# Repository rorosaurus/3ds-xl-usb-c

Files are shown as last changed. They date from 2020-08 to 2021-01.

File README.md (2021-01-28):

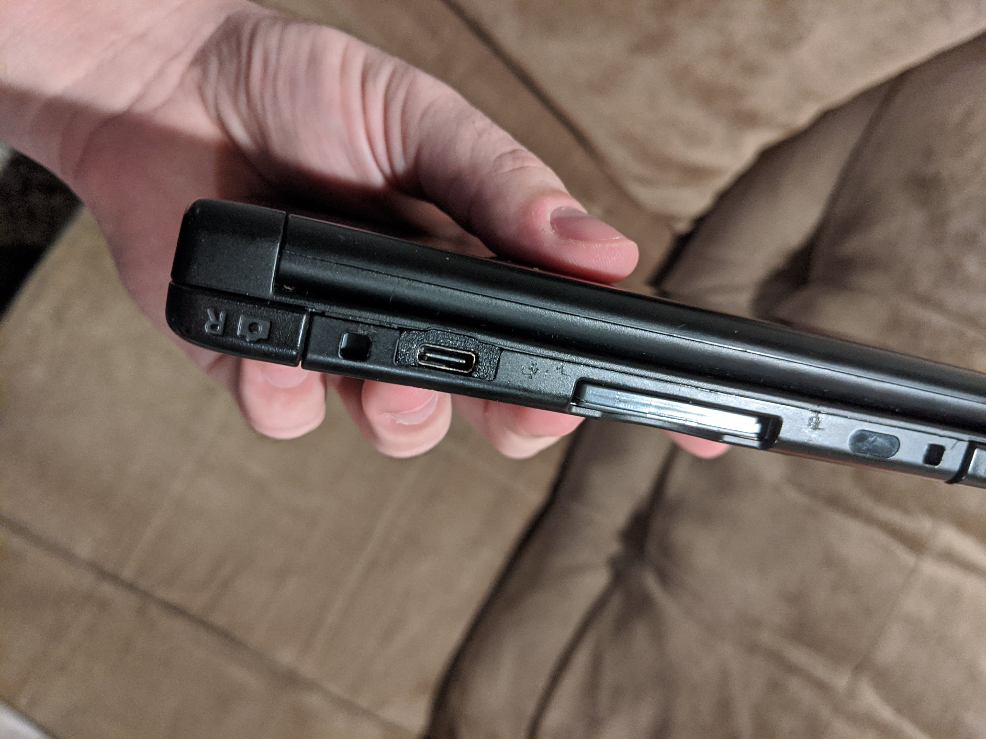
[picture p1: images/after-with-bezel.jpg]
After with bezel


**This mod requires some case trimming**, and I would recommend abandoning your charging dock contacts. More information available in the instructions page.

# Where to Buy

* USA: [Buy on Amazon](https://smile.amazon.com/dp/B08RN6LDVH) - [(Why Amazon?)](https://github.com/rorosaurus/gba-sp-usb-c/blob/master/why-sell-on-amazon.md)
* Any other Country: [Buy on Tindie](https://www.tindie.com/products/22543/) - (I will restock occasionally!)

## The truly universal USB-C dream is finally realized for your Nintendo 3DS XL!

Charge your Nintendo 3DS XL with USB-C, using any USB-C cable and charger! If it fits, it'll charge! Finally you can stop carrying around that extra proprietary cable!

My design is inspired by [this existing PCB](https://oshpark.com/shared_projects/I6UOH6gb) that only works with ````USB-A -> USB-C```` cables. In my opinion, if you're gonna future-proof your 3DS XL, you shouldn't remain reliant on Type-A!

My PCB works with ````USB-C <-> USB-C```` cables as well, so you can use ANY USB-C cable/charger to charge it! I've also verified it works with ````USB-A -> USB-C```` cables, Quick Charge, and USB-PD! That means if your charger or USB battery pack offers 5V/9V/12V/etc., it will recognize the 3DS XL can only accept 5V and charge accordingly.

**No 3D-printed part is included**, but the file is available for you to print yourself, if you want.

# Compatibility

This is designed for installation in any Nintendo 3DS XL (SPR-001).

This mod is not compatible with: 2DS, New 2DS XL, New 3DS, New 3DS XL.

This mod is not compatible with the original Nintendo 3DS. For the original 3DS, I recommend this mod by makho: [makhowastaken/3DS_C](https://github.com/makhowastaken/3DS_C/)

# Charge Speed

This console's original charger (WAP-002) outputs up to 900mA at 4.6V. According to the USB-C spec, this mod will allow charging at up to 500mA at 5V. This is, on paper, 40% slower charging than with the WAP-002.

However, in my testing, my console consumed 800mA at 5.1V, charging just as fast as the WAP-002. So please keep in mind that your mileage may vary, based on what USB charger you use and how precisely that charger follows the USB specification. Just be aware in the worst case, your console might charge a little slower.

# Disclaimer

Modify your console at your own risk! This product is provided "as is", with no warranty - express or implied. That said, if you have any issues or questions, don't hesitate to reach out!

# Installation

Instructions for assembly/installation can be found in [INSTALLATION.md](https://github.com/rorosaurus/3ds-xl-usb-c/blob/master/INSTALLATION.md)

# License

If you have improvements, please modify these design files and share any improvements openly/freely with the community (via a pull request or another public repository)!

You are not permitted to profit off of this design or use it in any commercial venture.

[Full license information.](https://github.com/rorosaurus/3ds-xl-usb-c/blob/master/LICENSE.md)

# Thanks

Thank you to [makho](https://www.youtube.com/channel/UC5FYpo9lFqK1Y7wqjPuANFw) and [BlindEye/Hidarite](https://www.tindie.com/stores/hidarite/) for the original PCB inspiration!

# Other Gameboy Mods

[Mods - Game Boy Subreddit Wiki](https://www.reddit.com/r/GameBoy/wiki/mods)

## My Other Gameboy Mods

* [USB-C Mod for Gameboy Advance SP (and original Nintendo DS)](https://github.com/rorosaurus/gba-sp-usb-c/)
* [USB-C Mod for Nintendo DS Lite](https://github.com/rorosaurus/nds-lite-usb-c/)
* [USB-C Mod for Nintendo 3DS XL](https://github.com/rorosaurus/3ds-xl-usb-c/)
* [List of headphone jack mods for the Gameboy Advance SP](https://github.com/rorosaurus/gba-sp-headphone-jack/)

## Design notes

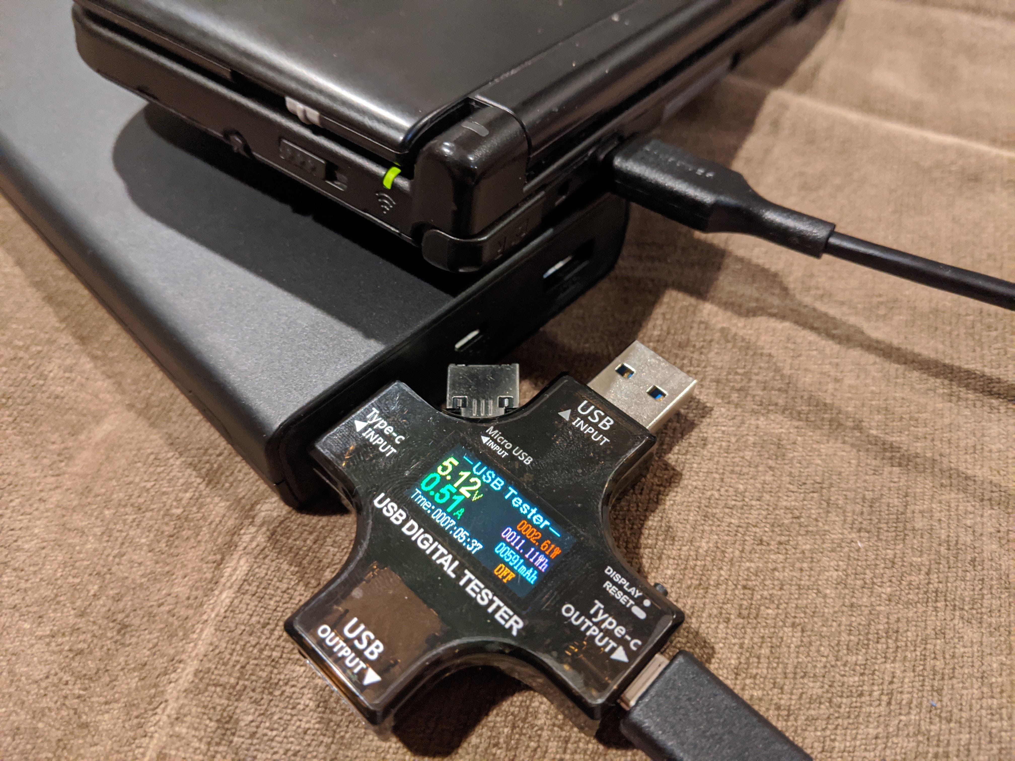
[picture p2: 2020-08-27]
images/after-charging-2.jpg

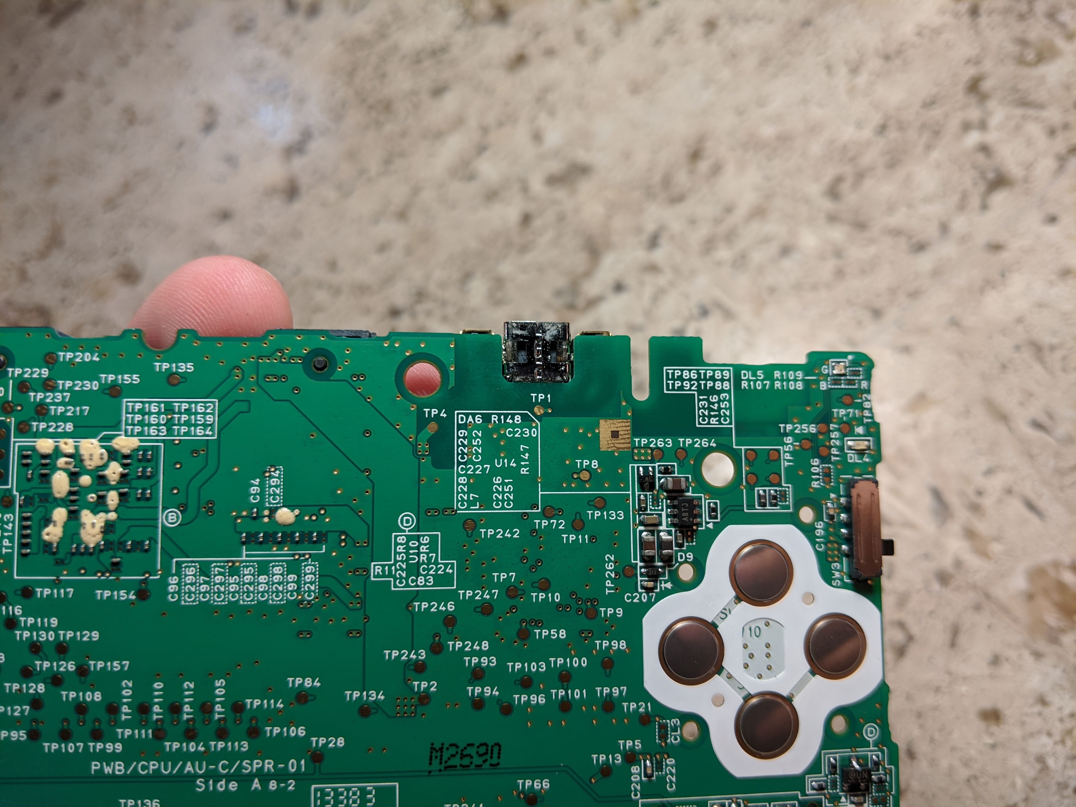
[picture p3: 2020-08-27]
images/before-port-bottom.jpg

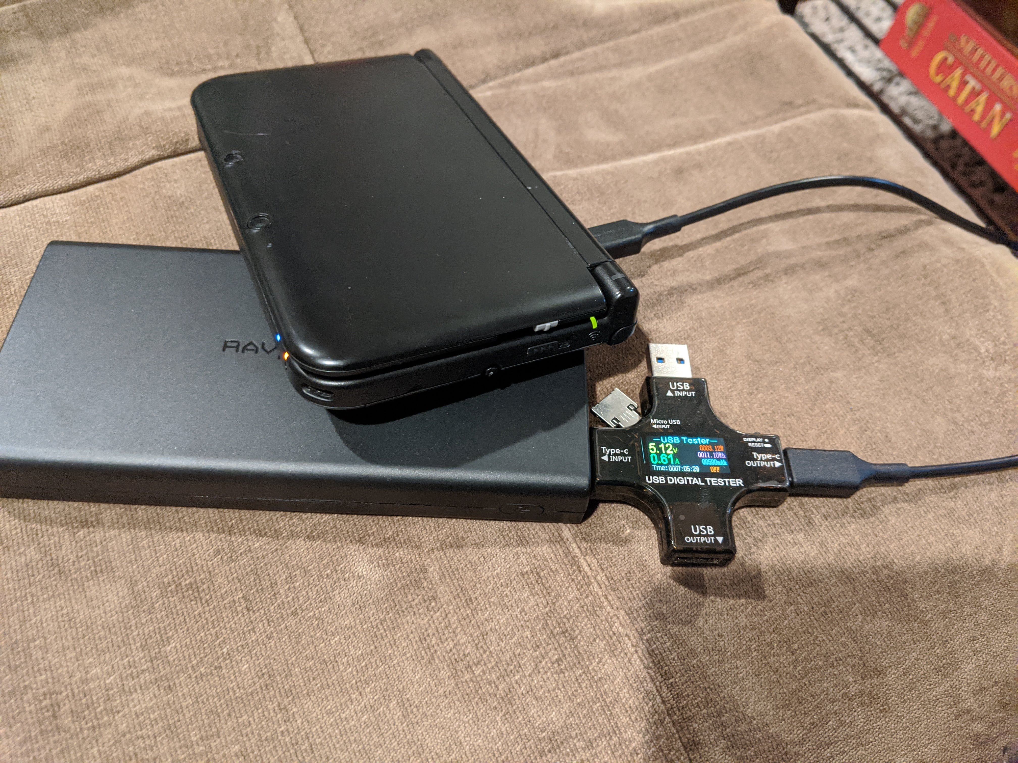
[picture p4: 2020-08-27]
images/after-charging-1.jpg

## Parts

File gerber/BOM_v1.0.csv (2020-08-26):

ID | Name | Designator | Footprint | Quantity | Manufacturer Part | Manufacturer | Supplier | Supplier Part
1 | TYPE-C-31-M-16 | USB1 | TYPE-C-SMD_TYPE-C-31-M-16 | 1
2 | 5.1K | R2,R1 | R0402 | 2

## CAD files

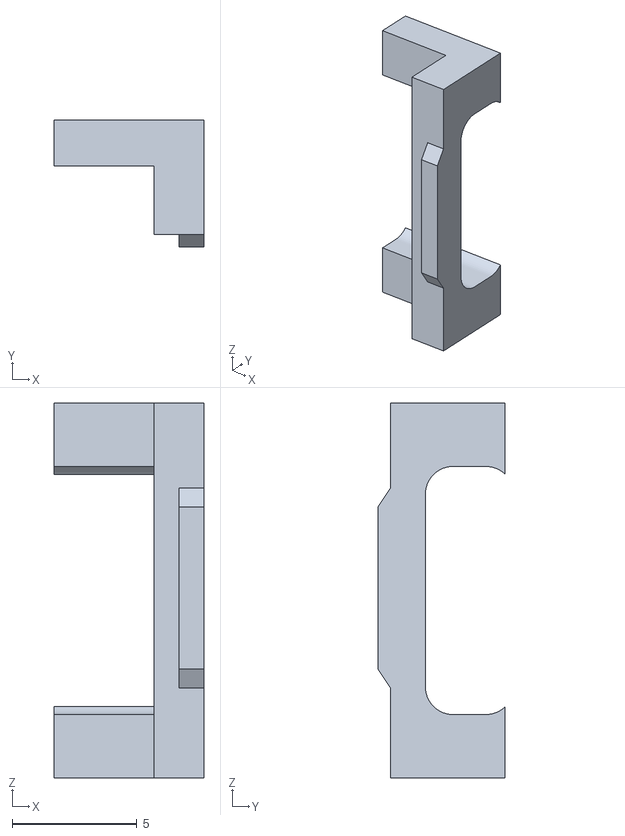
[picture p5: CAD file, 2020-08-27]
3DS-XL-USB-C-3D-printable-bezel.stl
6.00 x 5.10 x 15.0

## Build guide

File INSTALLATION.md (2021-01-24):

# Prep

Your PCBs might arrive with some [slight perforations, from the breakaway panelization design](https://github.com/rorosaurus/gba-sp-usb-c/blob/master/images/breakaway-perforations.jpg) during PCB manufacturing. These can be left alone, or optionally filed/sanded away.

The half-circle pad(s) behind the USB-C connector might have some debris across it. You can safely clear that away with a toothpick or similar - that will make it easier to solder to later.

# Test before you install!

I test every board before shipping, but you should be certain it still works before you install it! Plug it in to a ````Type-C <-> Type-C```` cable and USB-C power source. **Do not perform this test with a ````Type-A -> Type-C```` cable - that cable won't verify the board works for full USB-C!** Use a multimeter to measure the voltage across any of the grounded holes and the +5V half-circle in the back. Ensure it reads ~5V. Flip your USB-C cable the other way around and verify it still reads 5V! Alternatively, if you have a USB-C multimeter [like this](https://smile.amazon.com/gp/product/B07X3HST7V/) you can simply plug into that and read the display.

# Instructions

## A note on the charging dock contacts

I recommend abandoning the charging dock contacts if you install this mod. The USB-C port is ~8.8mm wide, the charging dock contacts are ~9.8mm apart. That means, properly centered, you'd have 0.5mm of plastic/prayers in-between your 5V dock contact and the grounded USB-C port frame. I personally don't want to deal with that likely short-circuit, but it might technically be possible if you are super careful and passionate about keeping the charging dock contacts. Make sure you harvest the contacts as you remove the standard charging port, and you'll need to modify the 3D printed bezel to accommodate those charging contacts.

## Step 1: Disassemble your 3DS XL and remove the motherboard

You can follow [this iFixit guide](https://www.ifixit.com/Guide/Nintendo+3DS+XL+Motherboard+Replacement/25399) for good disassembly instructions.

## Step 2: Remove the existing charge port

IMO, this is the hardest part by far. I found it easiest to solder-suck / wick the charging dock contacts first, then remove them.

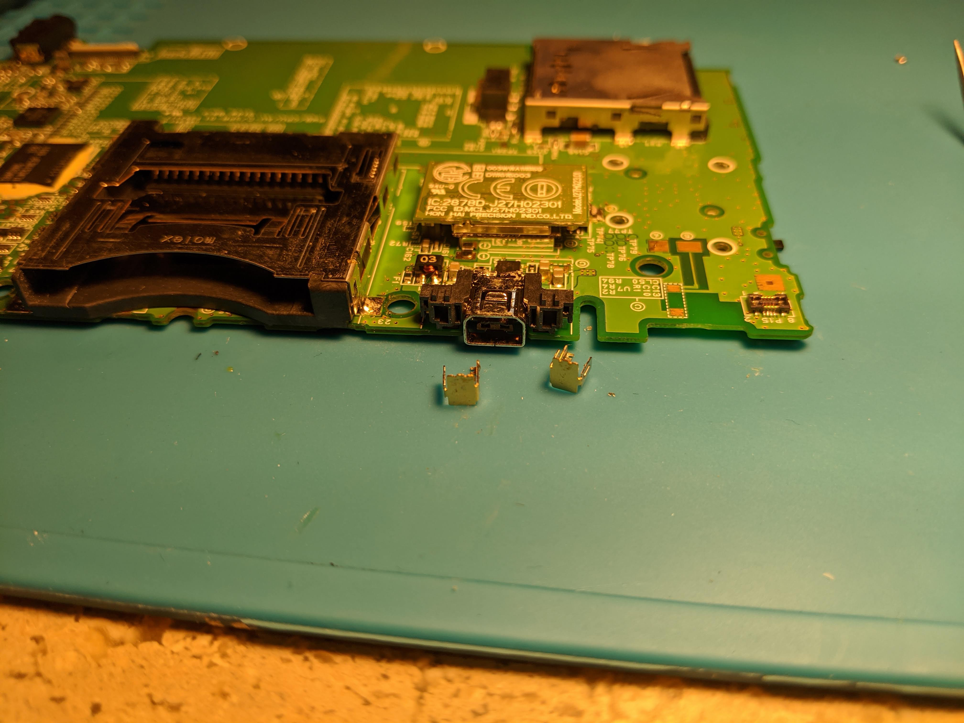
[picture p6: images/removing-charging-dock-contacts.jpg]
Removing charging dock contacts


Then I broke off and removed the charging dock contacts plastic support.

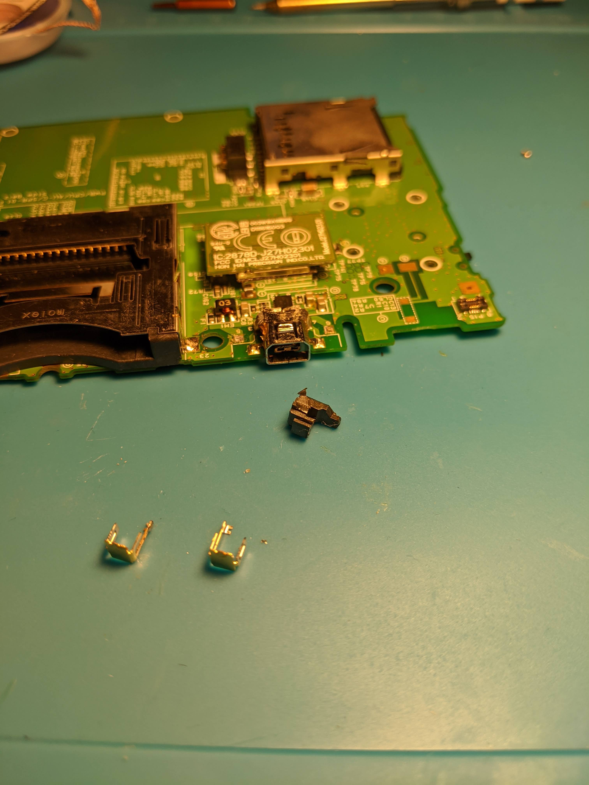
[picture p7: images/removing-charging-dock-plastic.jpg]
Removing charging dock plastic


Then I was able to solder-suck / wick the charging port itself and remove it. I should have been more patient to avoid damaging the pads a little bit.

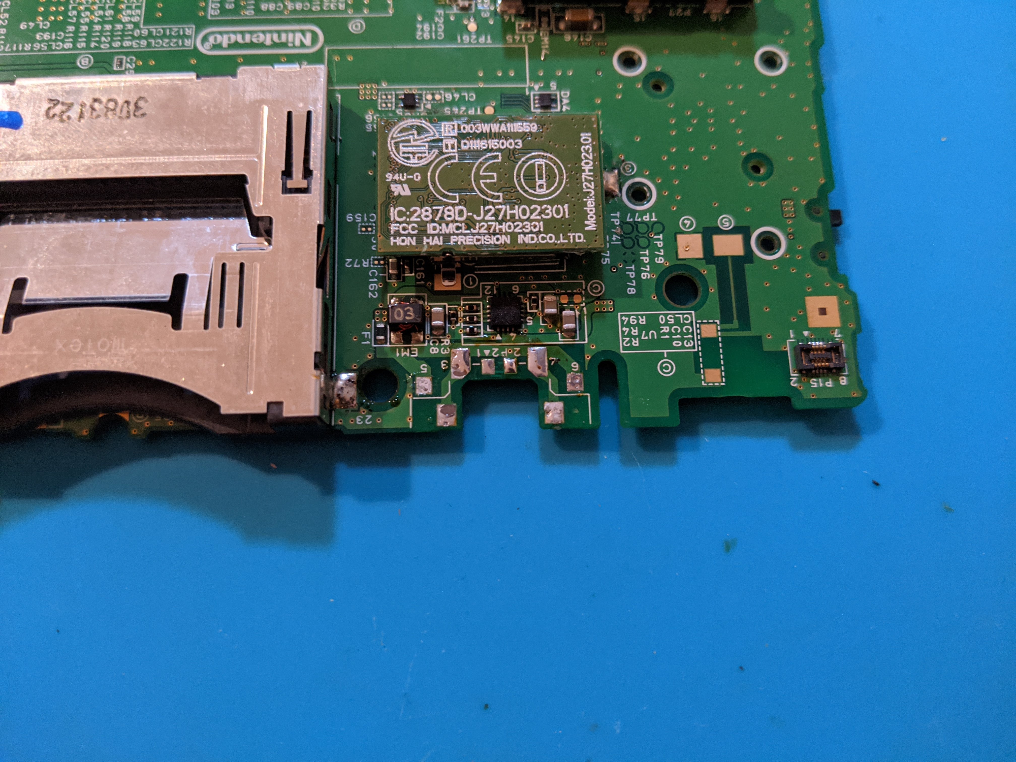
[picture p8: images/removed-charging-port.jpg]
Removed charging port


## Step 3: Prepare the new charge port

Assemble (and test!) the new USB-C charge port. That means positioning and soldering the brace into the perfect place, and adding the USB-C port and resistors if your mod came unassembled.

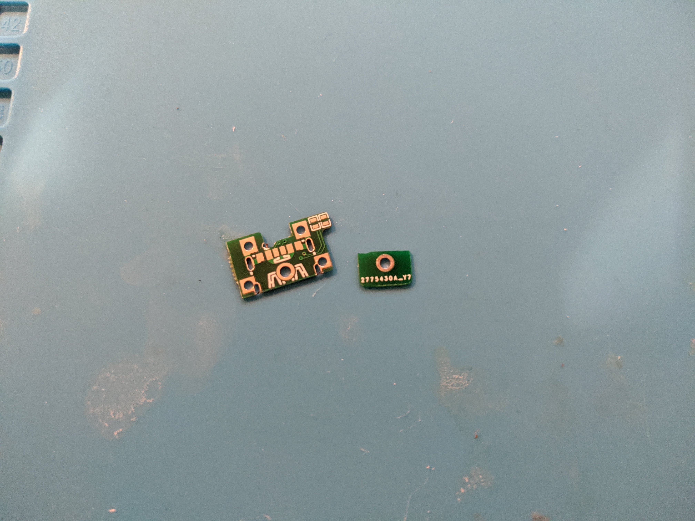
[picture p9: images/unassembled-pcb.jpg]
Unassembled PCB


Add some solder to sandwich the brace and the main PCB, lining the brace up flat with the edge of the main PCB, like this:

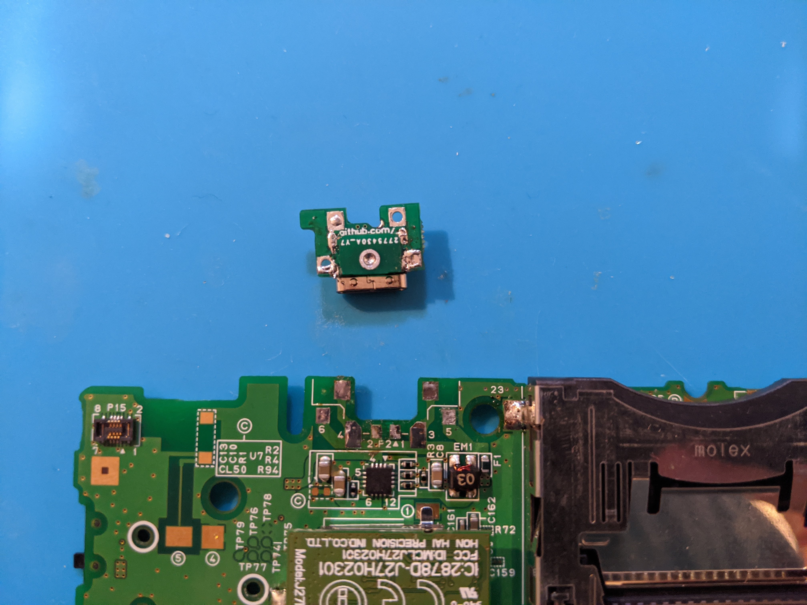
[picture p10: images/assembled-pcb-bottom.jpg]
Assembled PCB bottom


Ensure it fits well into the slot left by the old charging port.

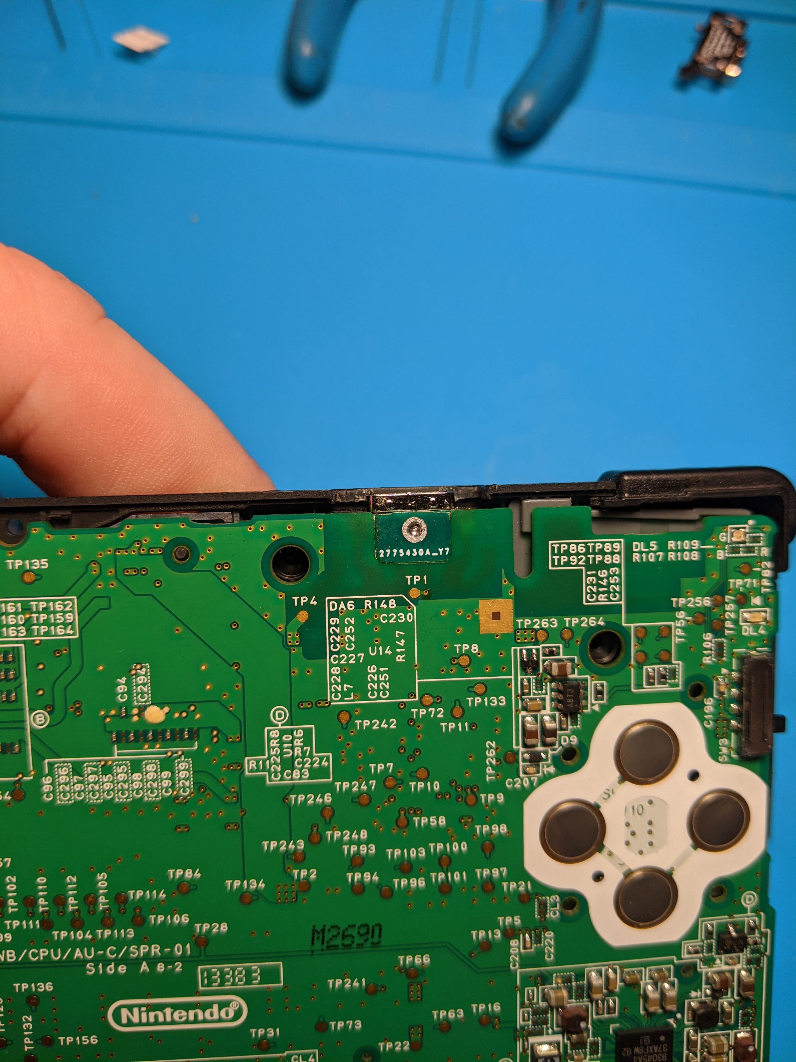
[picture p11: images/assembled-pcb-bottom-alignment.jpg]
Assembled PCB bottom alignment


Add your USB-C port and resistors if they aren't there already.

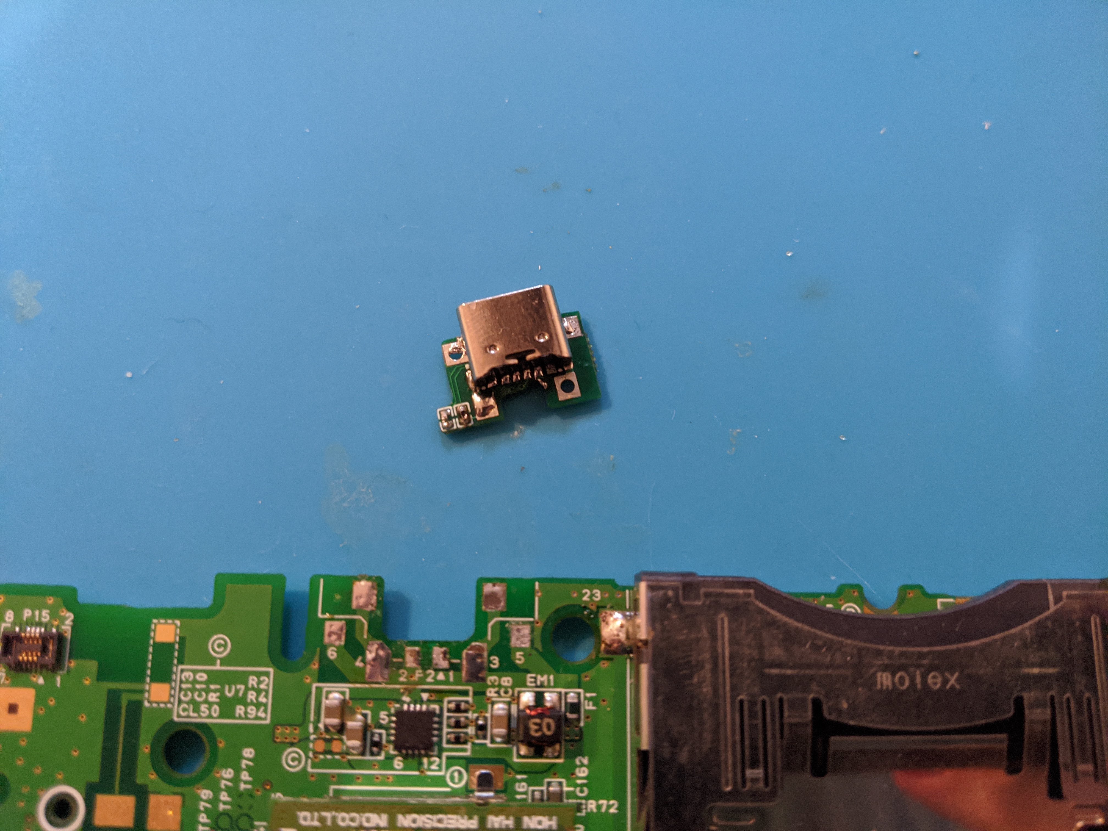
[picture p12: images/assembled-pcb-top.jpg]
Assembled PCB top


Ensure that your USB-C PCB and the motherboard are flat and flush before continuing.

## Step 4: Position and attach the new charge port

It should align like this, with holes lining up with the motherboard pads underneath.

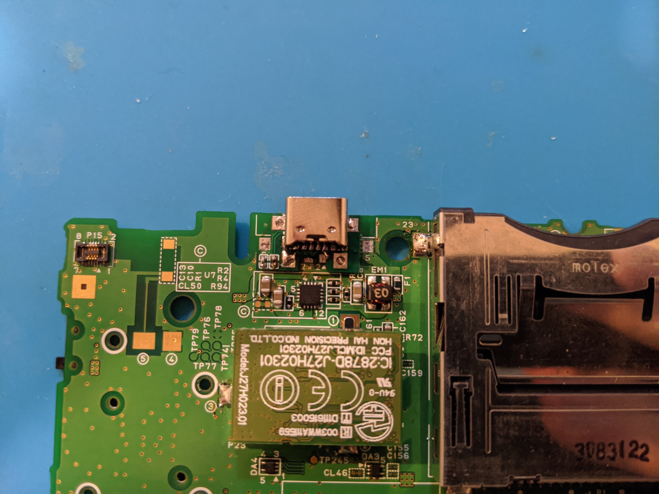
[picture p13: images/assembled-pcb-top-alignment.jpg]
Assembled PCB top alignment


Solder each hole, ensuring you heat up the pad underneath and allow solder to flow into the hole, securing the USB-C PCB to the motherboard at each of the 4 holes. Then finally use solder to attach the final half-circle pad to the 5V motherboard pad beneath it.

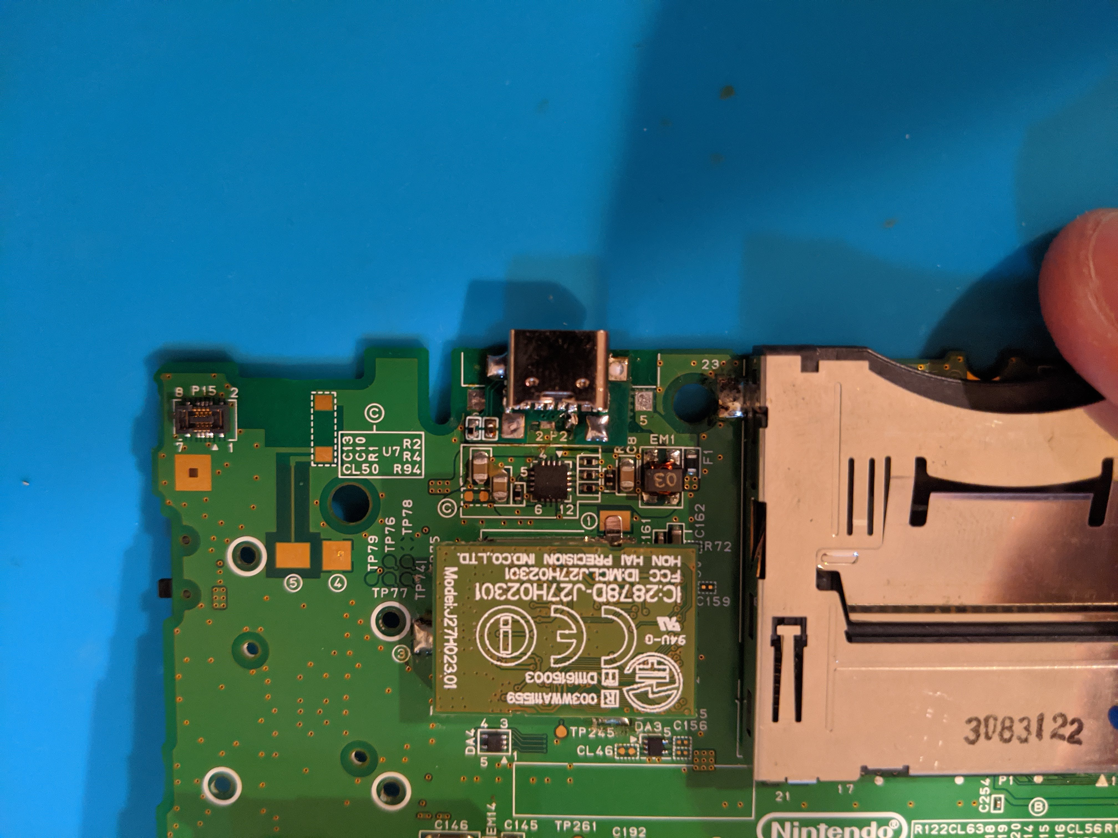
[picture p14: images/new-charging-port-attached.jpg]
New charging port attached


## Step 5: Case trimming

Use a dremel, sandpaper, and flush cutters to trim the case to fit the new port width. In my case, I chose to absorb the charging dock contacts as well, then fill it in with a 3D printed bezel.

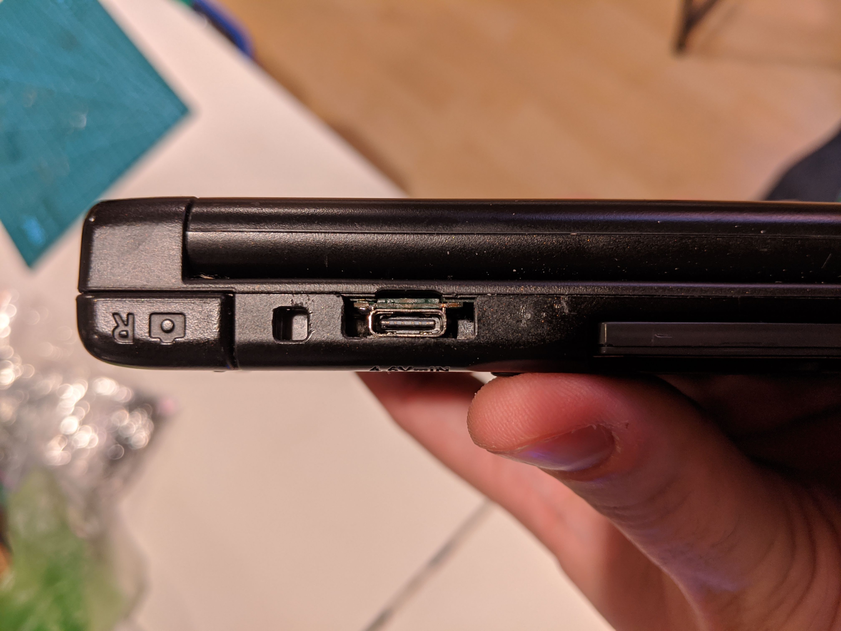
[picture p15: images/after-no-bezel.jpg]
After no bezel


## Step 6: 3D Print bezel to fill the gap

[3DS-XL-USB-C-3D-printable-bezel.stl](https://github.com/rorosaurus/3ds-xl-usb-c/blob/master/3DS-XL-USB-C-3D-printable-bezel.stl) is a 3D printable file that you can print/modify to fill in the remaining gap left by this USB-C mod.

After with bezel

# Troubleshooting

### Did you test the board before installing?

See above instructions! It's critical that you test this to ensure it was not damaged during shipping!

### Try with a different cable and/or charger

This mod should work with all combinations of cables and chargers, but try a different one to help diagnose the problem by eliminating variables.

### Flip the USB-C cable to the other orientation

If it works only in one orientation, then check the two small resistors. Ensure they are oriented properly and soldered to their pads. Reheat the solder joints with your iron and confirm continuity with your multimeter.

If it still only works in one orientation, sadly one of the six USB-C port pins has a bad connection to my PCB (damaged in shipping, most likely).

You can reflow these pins with your soldering iron, adding solder if needed. If you apply too much solder and the pins get bridged, you can use solder wick or a solder sucker to remove some.

### Did you accidentally lift up some of the original charging port's pads?

You can test with your multimeter that you have continuity from the USB-C port to the expected destination. You'll have to follow the traces or look up where they lead. You can often rewire directly to the destination if you've messed up the original charging port's pad.

### You heard a "click" or your console is no longer powering on

You might have just blown a fuse. Check F1 (or similar) for continuity and replace the part if necessary (replacement part list in the [Game Boy Discord](https://discord.gg/gameboy)). After searching for and fixing the short that caused the fuse to blow, of course!

### Still stuck?

If you're still stuck, the friendly folks in #modding on the [Game Boy Discord](https://discord.gg/gameboy) might be able to help you. Make sure you are patient and respectful - and clearly describe the problem and what you have tried to solve it so far.

I'm always available through Amazon/Tindie as well!

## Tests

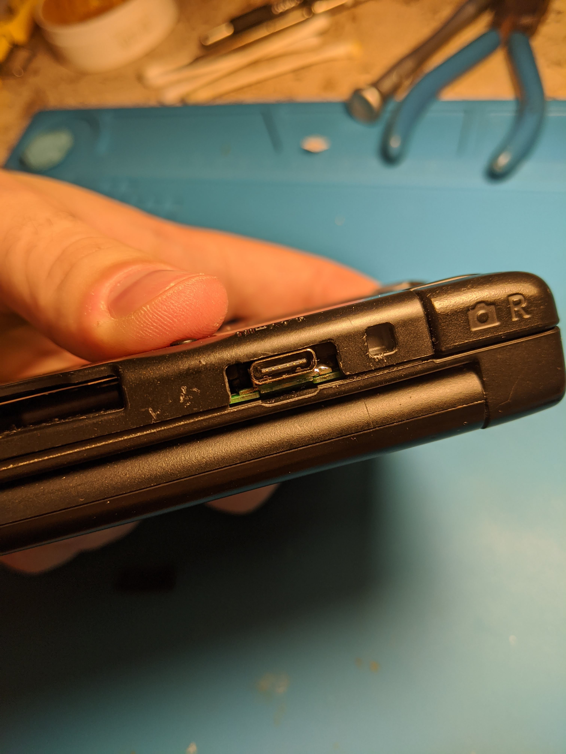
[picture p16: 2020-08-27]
images/testing-fit.jpg

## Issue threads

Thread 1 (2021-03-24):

New 2DS XL compatability?

zjDrummond, 2021-03-24:
How hard would it be to modify your board for installation into the New 2DS XL? Possible at all? Any chance we could fund a new board? I just bought a New 2DS XL, and I'd like to add it to my daily travel bad without the worry of charging issues.

rorosaurus, 2021-03-24:
I have no plans to create that at this time. It's probably do-able, just involves taking measurements and ensuring the parts line up. The PCB design (traces, holes) would be identical apart from the outer shape.

Closed 2021-03-24.

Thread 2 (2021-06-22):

New 3DS XL or 2DS XL?

YashMaster, 2021-06-22:
Hey there, you mentioned this is only for the original 3DS XL. Is it verified that this won't work with the New 3DS XL or 2DS XL? Do they not have the space for it? I wonder if it's possible to modify the design so it would work.

MEGAtheguy, 2021-07-05:
I have just successfully installed one on the New 3DS but I looked at the motherboard for the New 2DS XL and it doesn't seem to have the space for this breakout. There isn't enough clearance between where the port should be and the battery tray in the N2DS XL. I also looked at the board for the N3DS XL and it looks like it would NOT work because of clearance with other SMDs right next to the charging port

CSab6482, 2022-03-17:
u/amruthwo successfully installed this PCB in a 2DS XL (post [here](https://redd.it/s4udwe)).

Thinktank1803, 2022-04-13:
i have forked and proposed a change that should allow this sort of adapter to work on the new 3ds xl

Ardakilic, 2022-06-11:
I would love to hear a new 2ds XL version of this mod, if any at all.

Ardakilic, 2022-07-06:
Hey @Refuhr , Awesome! Also no jumpers involved and mounting is quite clever. Kudos! Thanks for the link! I already ordered some PCBs from Oshpark 🎉

By the way, do you think this connectors should work? https://imgur.com/a/dYrni2B I could find these in a local e-commerce site (the only ones available I guess) and it'll be way cheaper to order from China.

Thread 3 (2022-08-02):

Any chance you'll restock on Amazon?

joshbressers, 2022-08-02:
I know an issue isn't the best spot for this request, so apologies in advance.

I would love to use this mod, before I see about getting my own PCBs made, I wanted to check if you are planning to restock anytime soon

Thanks

MolassesLover, 2022-11-29:
Bumping this, I would pay good money for one of these PCBs!

halian, 2023-05-25:
Bumping, as the Amazon link has now rotted.

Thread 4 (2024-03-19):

Dimensions too small for JLCPCB assembly

ndrew222, 2024-03-19:
I’m looking to print this out using JLCPCB.
Two issues here,

1. I’m not sure what’s the expected thickness of the PCB (especially considering there’s a spacer)
2. The dimensions of the PCB is too small for assembly by JLCPCB (min. 10mm x 10mm). The PCB is 8.51mm x 21.33mm

I can see a few ways the PCB can be modified to make the size requirements, but as I currently don’t know how to use KiCad or EasyEDA, I’m unable to submit a PR.

I know it’s been 3 years since the last commit, but I hope you can help me out here.

PolyCatDev, 2025-03-13:
I don't know here. Sadly I had to have the boards printed without any parts. Others services sunch as PCBWay might offer assembly at this small scale

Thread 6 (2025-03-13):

Nothing mentioned about what resistors to use in assembly

PolyCatDev, 2025-03-13:
In the assembly instructions there is no mention of the resistors value and/or model number

PolyCatDev, 2025-03-13:
After some searching I found sources saying that 5.1k ohm resistors should be the correct ones.

Imma buy a breakout board I know has the right resistors, measure them and report back

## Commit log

2020-08-27 init instructions
    [3DS-USB-C-3D-printable-bezel.stl]
2020-08-29 rename repo
    [3DS-XL-USB-C-3D-printable-bezel.stl]
2021-01-28 add charging speed information
